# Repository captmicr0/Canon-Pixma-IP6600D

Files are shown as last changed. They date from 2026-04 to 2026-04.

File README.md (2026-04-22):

# Canon-Pixma-IP6600D
Software and 3D printed replacement parts for the Canon Pixma IP6600D.

## Resources
- http://pixma-faq.periastron.com/

  This resource was **invaluable**. It's only available on [archive.org](http://web.archive.org/web/20080105035258/http://pixma-faq.periastron.com/)

  I've created an [HTTrack backup](pixma-faq/index.html) of this archived website for safe keeping.

- https://www.thingiverse.com/thing:5336201
  
  This made creating the disk tray much easier as this card tray had most of the difficult features already completed.

  This repo has a [backup of the model](parts/card%20tray/PIXMA%20IP6600D%20Card%20Tray%20-%205336201.zip) for safe keeping.

# Replacement Parts
> [!TIP]
> All parts should be printed slowly with a 0.16mm layer height for best results.\
> My parts are designed with this layer height in mind.

## Card Tray
The only pre-existing part I could find for this printer was the PVC card tray on Thingiverse. I've included it in this repo for archival purposes.

It was only available as a STL, so I used FreeCAD to convert it into a STEP file. This is also included in the repo.

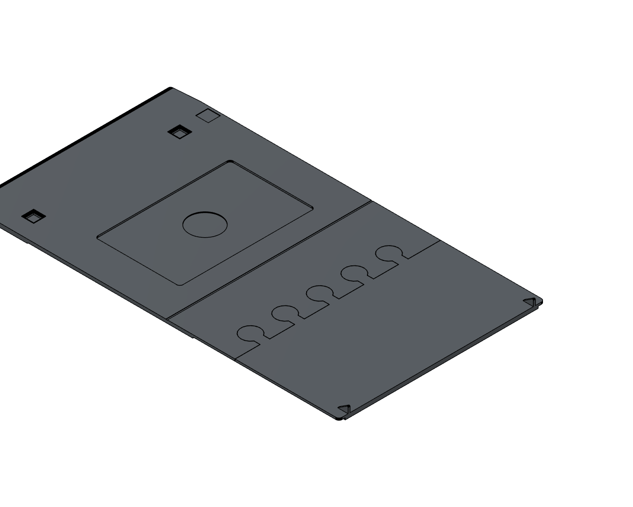
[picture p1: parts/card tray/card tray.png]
Card Tray (Parametric)


## Disk Tray
From this card tray, I created the elusive CDR disk tray based on the specifications found [here](https://web.archive.org/web/20080101103419/http://pixma-faq.periastron.com/3.html).

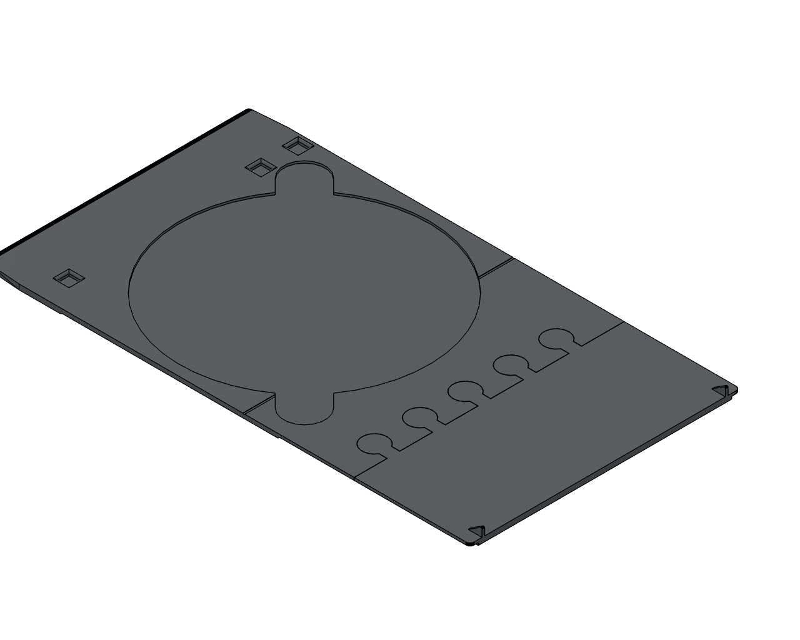
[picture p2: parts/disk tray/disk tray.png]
Disk Tray (Parametric)


## SD Card Door
My printer had a broken SD card door, so I recreated it as well. Unlike the original, there is no window on the door. I will probably never use the card reader feature, but I wanted my printer to look nice.

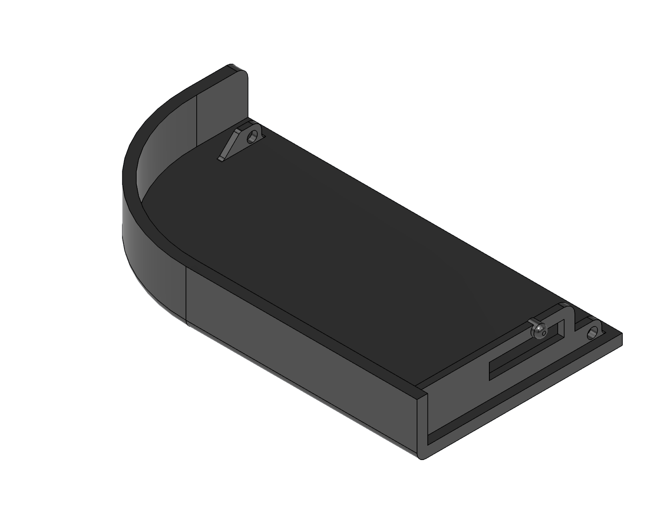
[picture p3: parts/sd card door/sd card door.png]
SD Card Door (Parametric)


## Automatic Slot Feeder (Paper Input) Tray
The hinge was broken on my paper input tray so I recreated the entire tray. I realized it was also missing the paper straightening flap that (apparently) automatically folds out. I recreated this flap from a few pictures, included in the repo now, I was able to find online. I also recreated the sliding extension piece so I had a 100% complete recreation of the entire paper input tray.

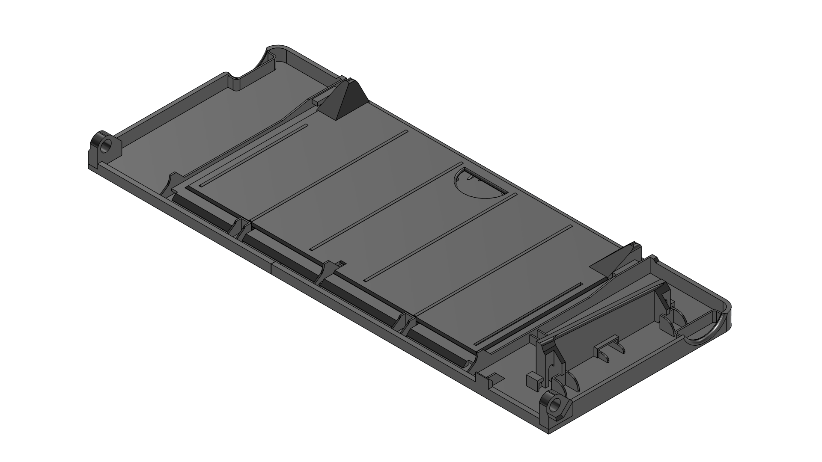
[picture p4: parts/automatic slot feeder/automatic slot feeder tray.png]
Automatic Slot Feeder (Paper Input) Tray (Parametric)


For the straighening/alignment flap you need a 1.5mm DIA x 10mm L metal rod and a torsion spring. The model uses McMaster-Carr Part # 9271K644 for the spring, which has a 1.7mm shaft DIA and ~9.5mm length length. 

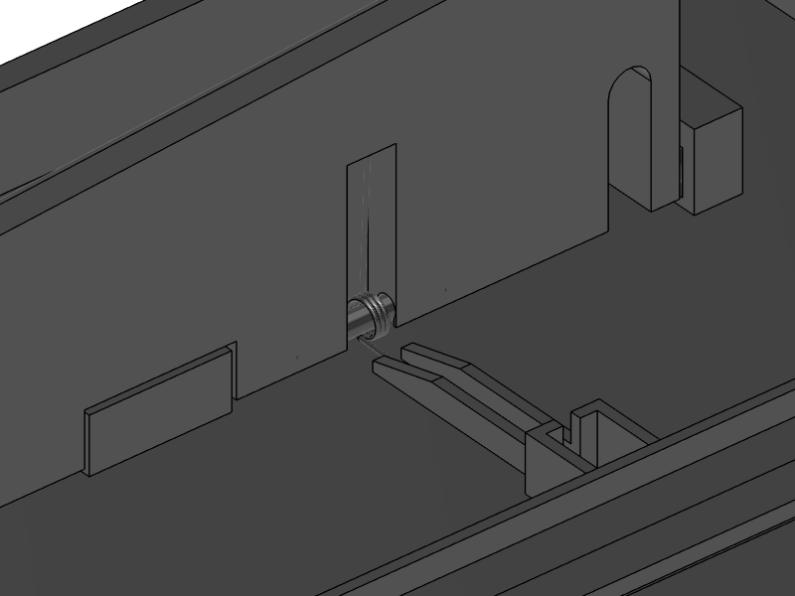
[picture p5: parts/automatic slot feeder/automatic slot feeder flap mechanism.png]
Automatic Slot Feeder (Paper Input) Flap Mechanism (Parametric)


# Software
The **latest** fully featured print driver available from Canon only supports Windows 7 32-bit. There are a few 64-bit drivers that I've tested on Windows 11 and none of them work.

The easiest way to deal with this is to create a Windows 7 32-bit virtual machine. After installing the driver you can use USB passthrough to access it from the virtual machine. 

I used Microsoft's IE9 (or IE10) Windows 7 virtual machine image. You can find more details here:
https://github.com/magnetikonline/linux-microsoft-ie-virtual-machines

After importing the OVA into your virtual machine software (i.e. VirtualBox), you can activate it with [massgrave.dev](https://massgrave.dev/) using the tradition (offline) activation method.

## Driver
Next, install the [Canon IP6600D Print Driver](software/ip6600dvst200ej.exe). I selected the Europe region during install, but this shouldn't matter.

## CD Label Software
For printing the lables, I used the [Canon-provided CD-LabelPrint V1.0.2 software](software/CD-LabelPrint.Win.V1.0.2_E.exe).

## Acrobat Reader
I also installed [Acrobat Reader 9.4.0](software/9.4.0_AdbeRdr940_en_US.exe) so I could print PDF documents.

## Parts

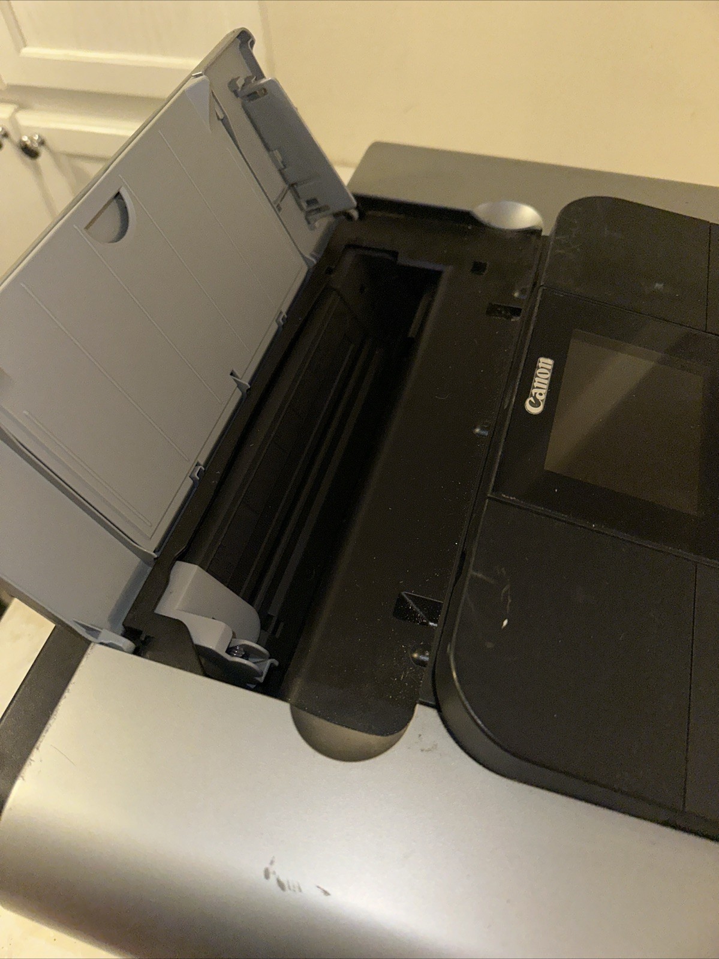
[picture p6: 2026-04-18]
parts/automatic slot feeder/reference pictures/missing part view.jpg

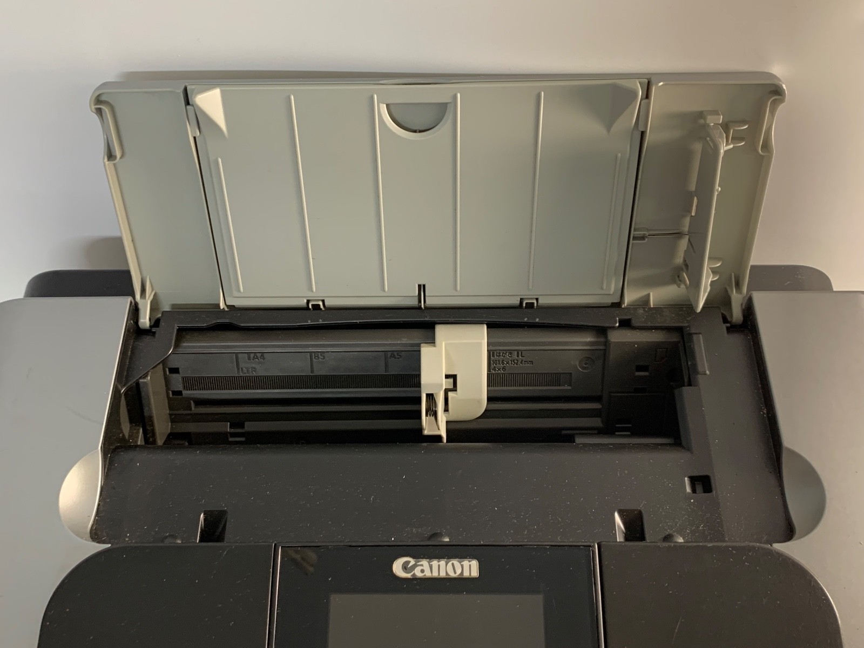
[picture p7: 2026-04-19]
parts/automatic slot feeder/reference pictures/s-l1600.jpg

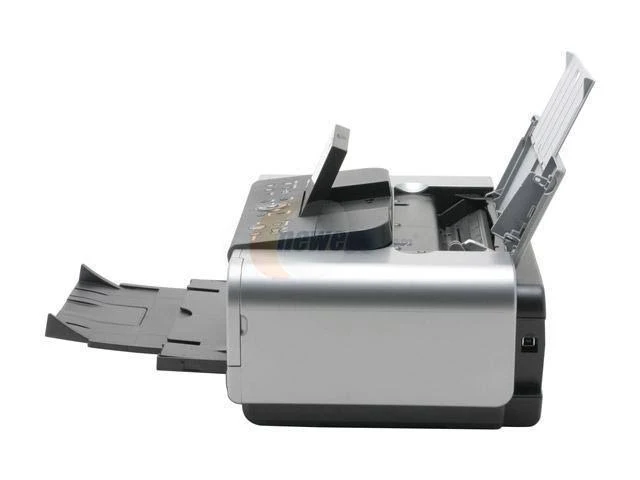
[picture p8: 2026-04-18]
parts/automatic slot feeder/reference pictures/right side.webp

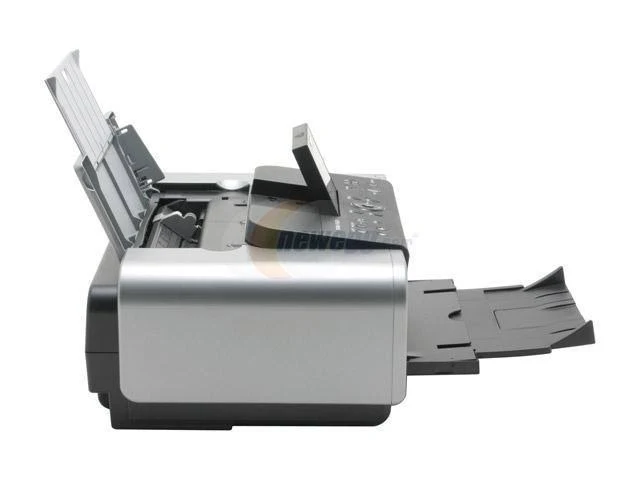
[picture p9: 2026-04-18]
parts/automatic slot feeder/reference pictures/left side.webp

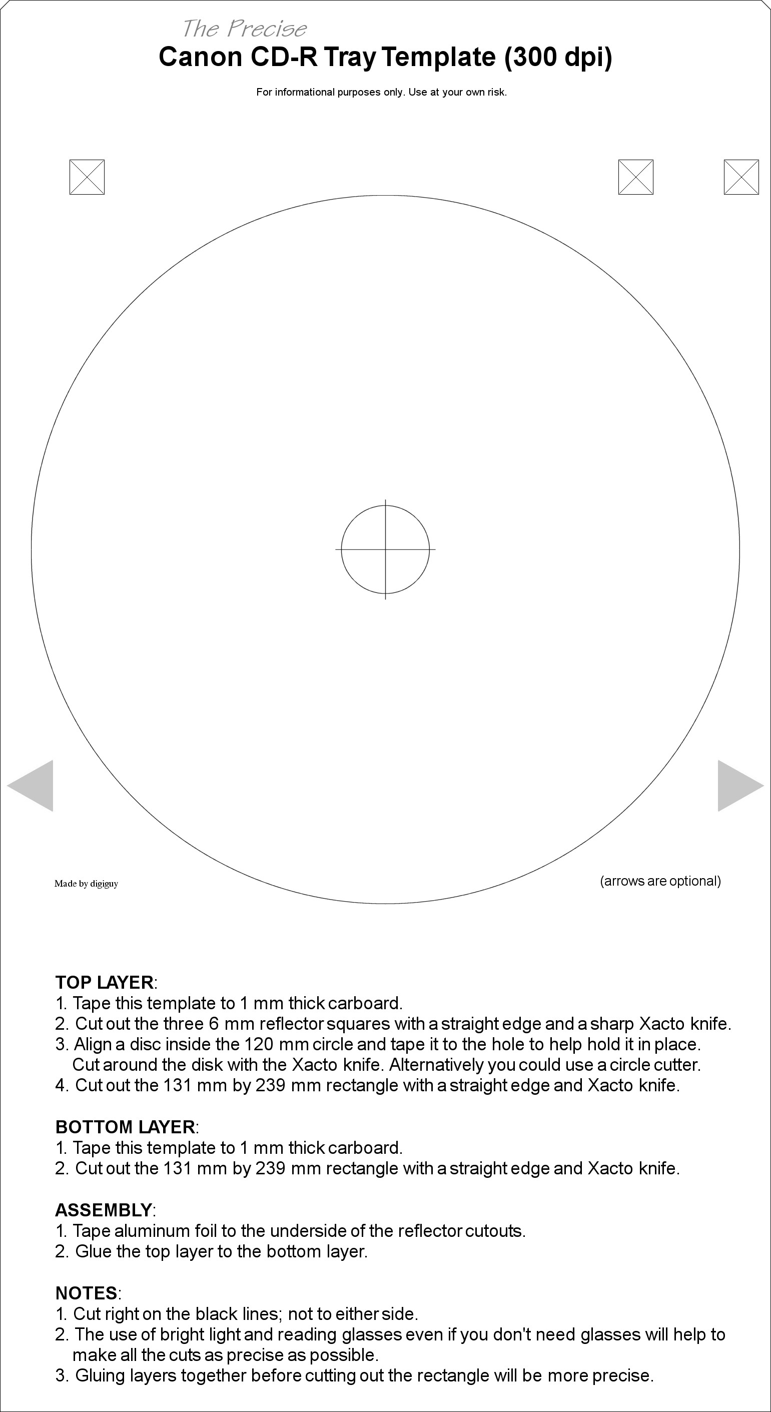
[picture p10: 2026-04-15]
parts/disk tray/3-3-big.jpg

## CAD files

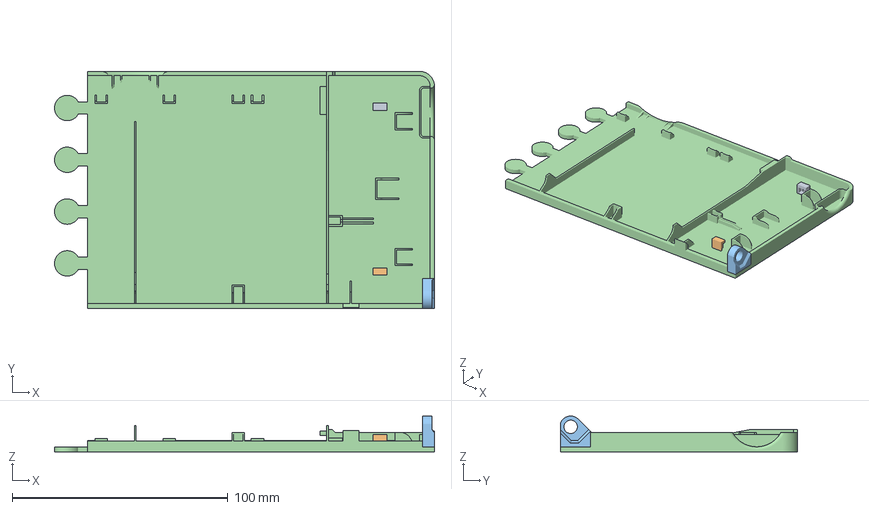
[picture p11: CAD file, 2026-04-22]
parts/automatic slot feeder/Right Tray.3mf
176.1 x 110.0 x 16.6 mm
Flap Hinge (1)
Flap Hinge
Hinge
Tray (1)

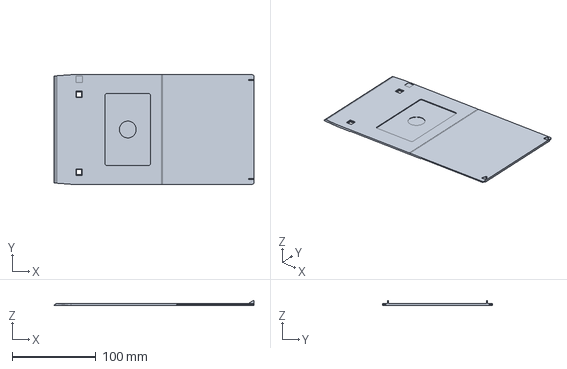
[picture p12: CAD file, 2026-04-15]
parts/card tray/stl2step/Unnamed.FCStd
238.5 x 130.7 x 6.38 mm

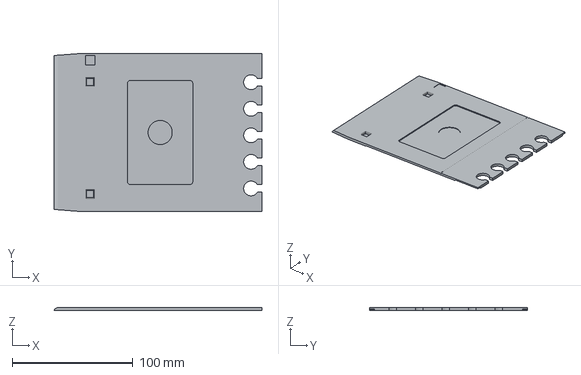
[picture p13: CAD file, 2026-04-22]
parts/card tray/Tray 1.3mf
172.4 x 130.7 x 2.50 mm

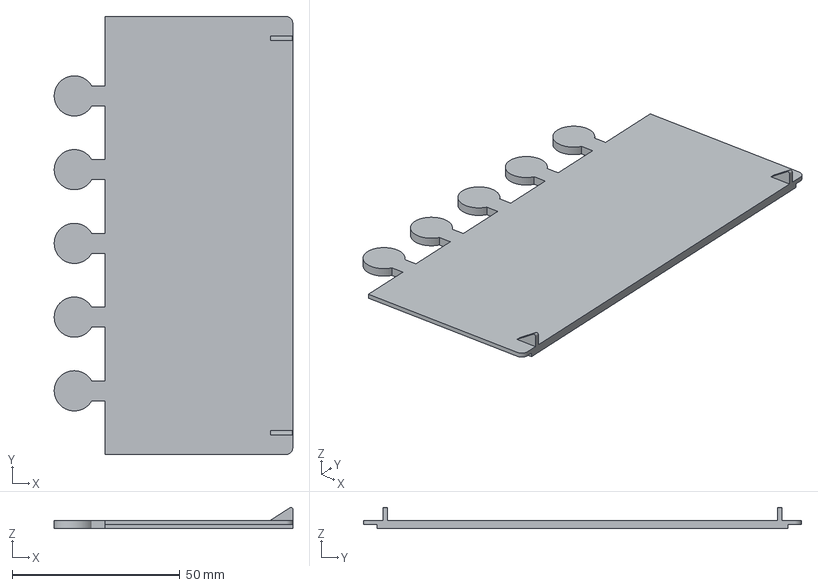
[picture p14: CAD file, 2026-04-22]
parts/disk tray/Tray 2.3mf
71.2 x 130.7 x 6.38 mm

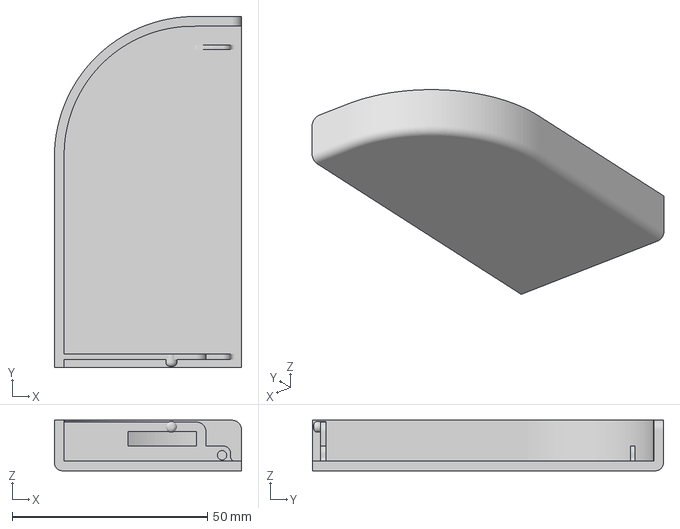
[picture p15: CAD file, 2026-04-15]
parts/sd card door/SD Card Door.3mf
48.0 x 90.0 x 13.0 mm

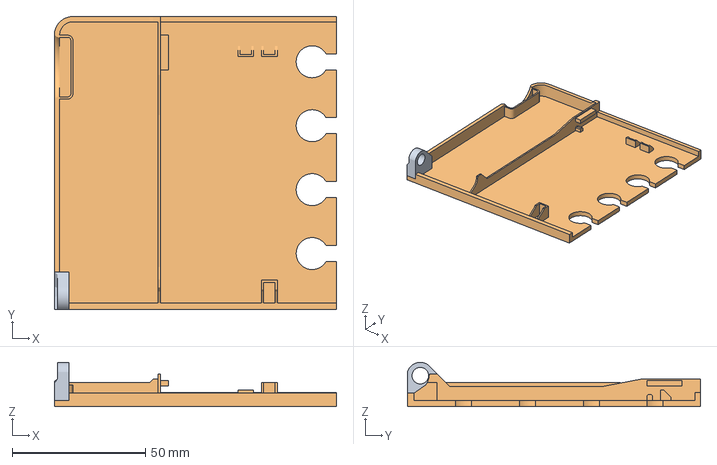
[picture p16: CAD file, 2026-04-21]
parts/automatic slot feeder/Left Tray.3mf
106.0 x 110.0 x 16.6 mm
Hinge (1)
Tray

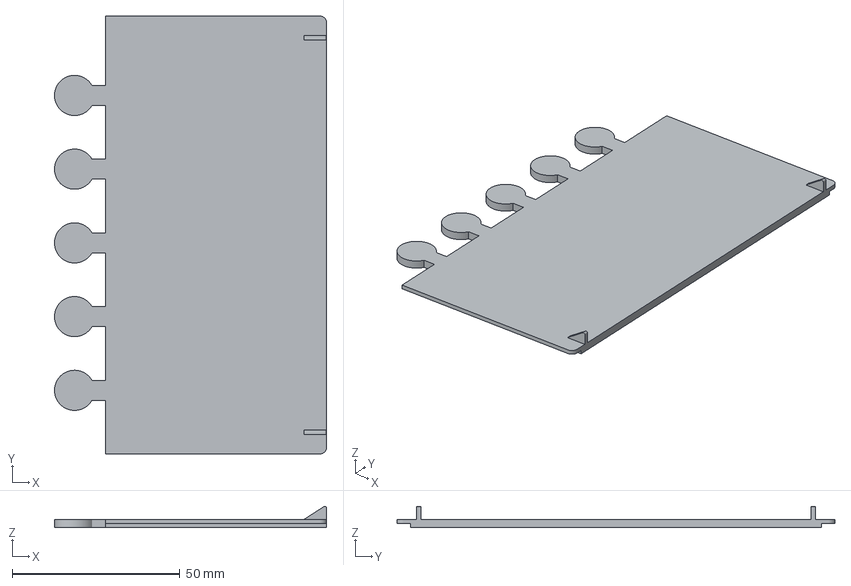
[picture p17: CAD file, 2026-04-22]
parts/card tray/Tray 2.3mf
81.2 x 130.7 x 6.38 mm

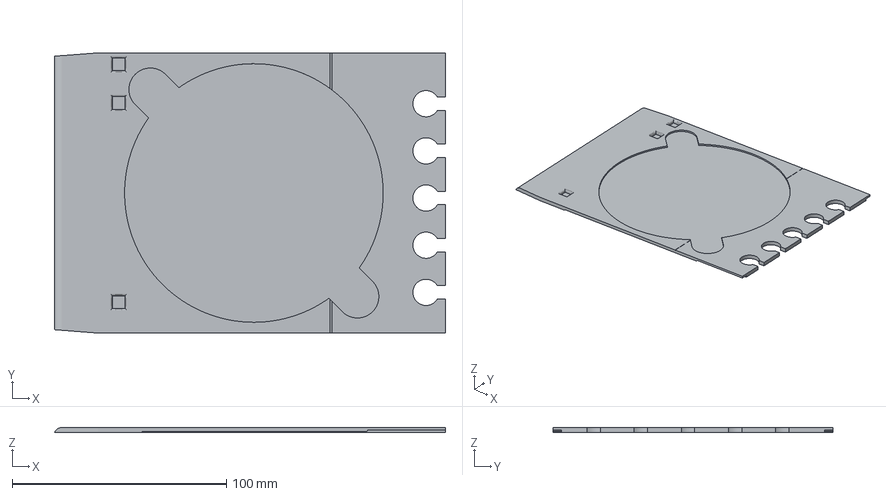
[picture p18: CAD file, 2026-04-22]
parts/disk tray/Tray 1.3mf
182.4 x 130.7 x 2.50 mm

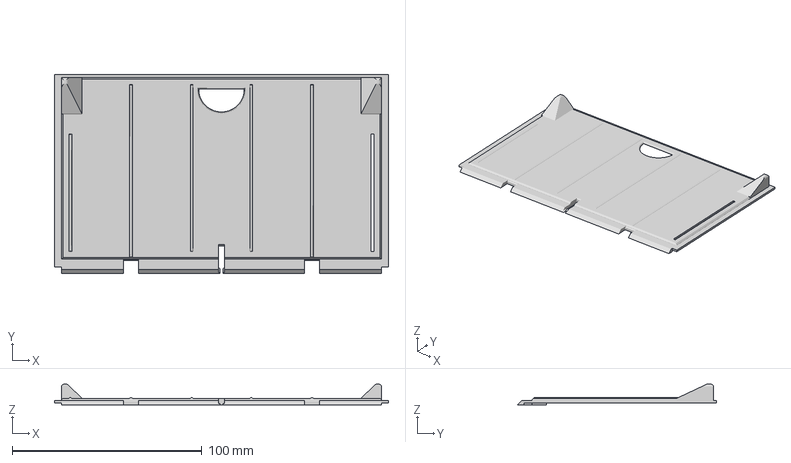
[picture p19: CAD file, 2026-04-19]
parts/automatic slot feeder/Slide.3mf
176.0 x 105.0 x 11.0 mm

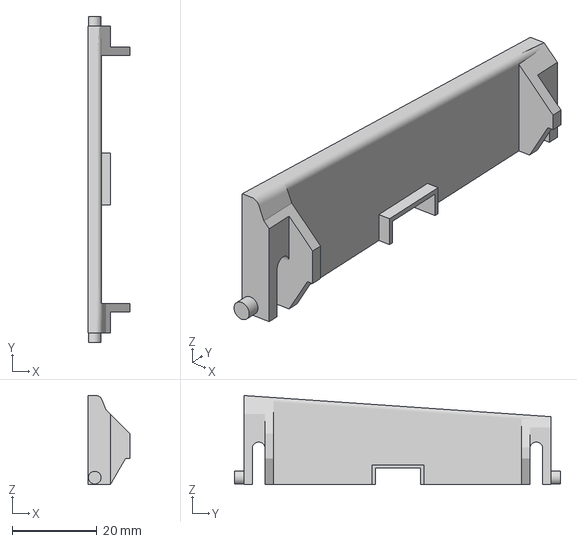
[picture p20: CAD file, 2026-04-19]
parts/automatic slot feeder/Flap.3mf
9.92 x 76.9 x 21.0 mm

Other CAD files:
parts/card tray/stl2step/Unnamed-IP6600D_card_tray002.step
parts/automatic slot feeder/Automatic Slot Feeder Tray.f3d
parts/card tray/Card Tray.f3d
parts/card tray/stl2step/Unnamed-IP6600D_card_tray002.3mf
parts/disk tray/Disk Tray.f3d
parts/sd card door/SD Card Door.f3d

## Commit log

2026-04-19 finished ASF tray and subparts
    [Automatic Slot Feeder Tray.3mf, Automatic Slot Feeder Tray.f3d, Entire Tray.3mf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]
2026-04-20 split paper input tray to fit on smaller print bed
    [Automatic Slot Feeder Tray.3mf, Automatic Slot Feeder Tray.f3d, Entire Tray.3mf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]
2026-04-21 completed ASF, test prints fit well. updated readme
    [Automatic Slot Feeder Tray.f3d, Entire Tray.3mf, Left Tray.3mf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]
2026-04-22 paper input tray flap hinges moved 1mm to left to match original
    [Automatic Slot Feeder Tray.f3d, Entire Tray.3mf, Right Tray.3mf]
2026-04-22 fixed middle slide rail
    [Automatic Slot Feeder Tray.f3d, Right Tray.3mf]
2026-04-22 modified disk and card tray to use better split joint
    [Card Tray.f3d, Disk Tray.f3d, Tray 1.3mf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]
